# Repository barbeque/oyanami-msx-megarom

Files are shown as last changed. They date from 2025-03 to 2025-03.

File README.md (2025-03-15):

# Oyanami
TODO: Overview

This project was built as part of a [Leaded Solder blog](https://www.leadedsolder.com/) entry.

Articles so far about this project:
 - [Oya, I've heard of Mega-ROMs](https://www.leadedsolder.com/2024/09/03/msx-megarom-oyanami.html)

If it's useful to you, please consider supporting the blog through [Patreon](https://patreon.com/leadedsolder) or [Ko-Fi](https://ko-fi.com/leadedsolder). All money goes directly to future projects like this.

## Build It Yourself!
The Oyanami board is open-source. You can grab the Gerber files from [the Releases page](https://github.com/barbeque/oyanami-msx-megarom/releases) and send those to a fabricator of your choice.

Recommended settings: 

 - ENIG or Hard Gold finishing
 - Beveled or chamfered edge connector

## Known Working Games
 - 1942 (MSX2 version only)
 - Arkanoid 2 - Revenge of DOH
 - Ashguine Story I
 - Bubble Bobble
 - Contra (MSX2; CRC32: 4e82660d)
 - Cyborg Z
 - Digital Devil Story
 - Dragon Buster
 - Dragon Quest 1 (both MSX1, MSX2 versions)
 - Druid
 - F1 Spirit
 - Family Billiards
 - Fantasy Zone 1
 - Final Zone Wolf
 - Ganbare Goemon
 - Gangjeol Robocop
 - Genesis - Dawn of a New Day
 - Hai No Majutsushi
 - Hinotori
 - King Kong 2
 - King's Valley 2 Edit Contest Edition
 - King's Valley 2 (MSX2 only)
 - Metal Gear (CRC32: e85c5731)
 - Mr. Ninja Ashura's Chapter
 - Nemesis (CRC32: 4dfcc009)
 - Nemesis 2
 - Parodius
 - Pengo
 - Penguin Adventure
 - Pennant Race
 - Return of Jelda
 - Salamander
 - Spy vs. Spy II (64kB Konami-mapper version)
 - Seikima 2 Special - Tetsuji
 - Street Master
 - Super Bioman 4
 - Super Boy 3
 - Super Runner
 - Tengoku Yoitoko - Heaven
 - The Fairyland Story
 - The Fantasm Soldier Valis
 - The Maze of Galious: Knightmare 2
 - Topple Zip MSX2
 - Treasure of USAS (MSX2)
 - Vampire Killer (MSX2)
 - Wonsiin
 - Young Sherlock: Legacy of Doyle

This is an incomplete list, please submit pull requests for any other games you have tested.

## Bill of Materials

| Position | Component | Digi-Key link | Comments  |
|---|---|---|---|
| U1 | SST39SF040 DIP EEPROM | | |
| U3 | 74LS670 DIP | | Do not use ALS, see below |
| U4 | 74LS02 DIP | | |
| C... | 0.1µF through-hole ceramic capacitor | | |
| RN1 | 10kΩ x 8 (9-pin SIP) resistor network | | |
| SW1 | 2-pin DIP switch | | |

I also recommend getting a case for the PCB from somewhere like [Retro Game Restore](https://retrogamerestore.com/store/msx_cart_shell).

Beware! Using socketed ICs may not leave enough vertical height for a standard Konami-style cartridge case to close.

74ALS670 has been reported not to work with MSX Turbo-R systems. Please use only the LS variant.

## Version History
### v1.2: In development
Still in development. Adds write-enable pin to ROM to support in-MSX reflashing.

### v1.1: July 2024
Initial working version. Supports read-only games.

## Special Thanks
 - bsittler for the help and inspiration to get this figured out;
 - Pax for CRC32s;
 - Annual_Bottle_4639 on Reddit for testing additional games

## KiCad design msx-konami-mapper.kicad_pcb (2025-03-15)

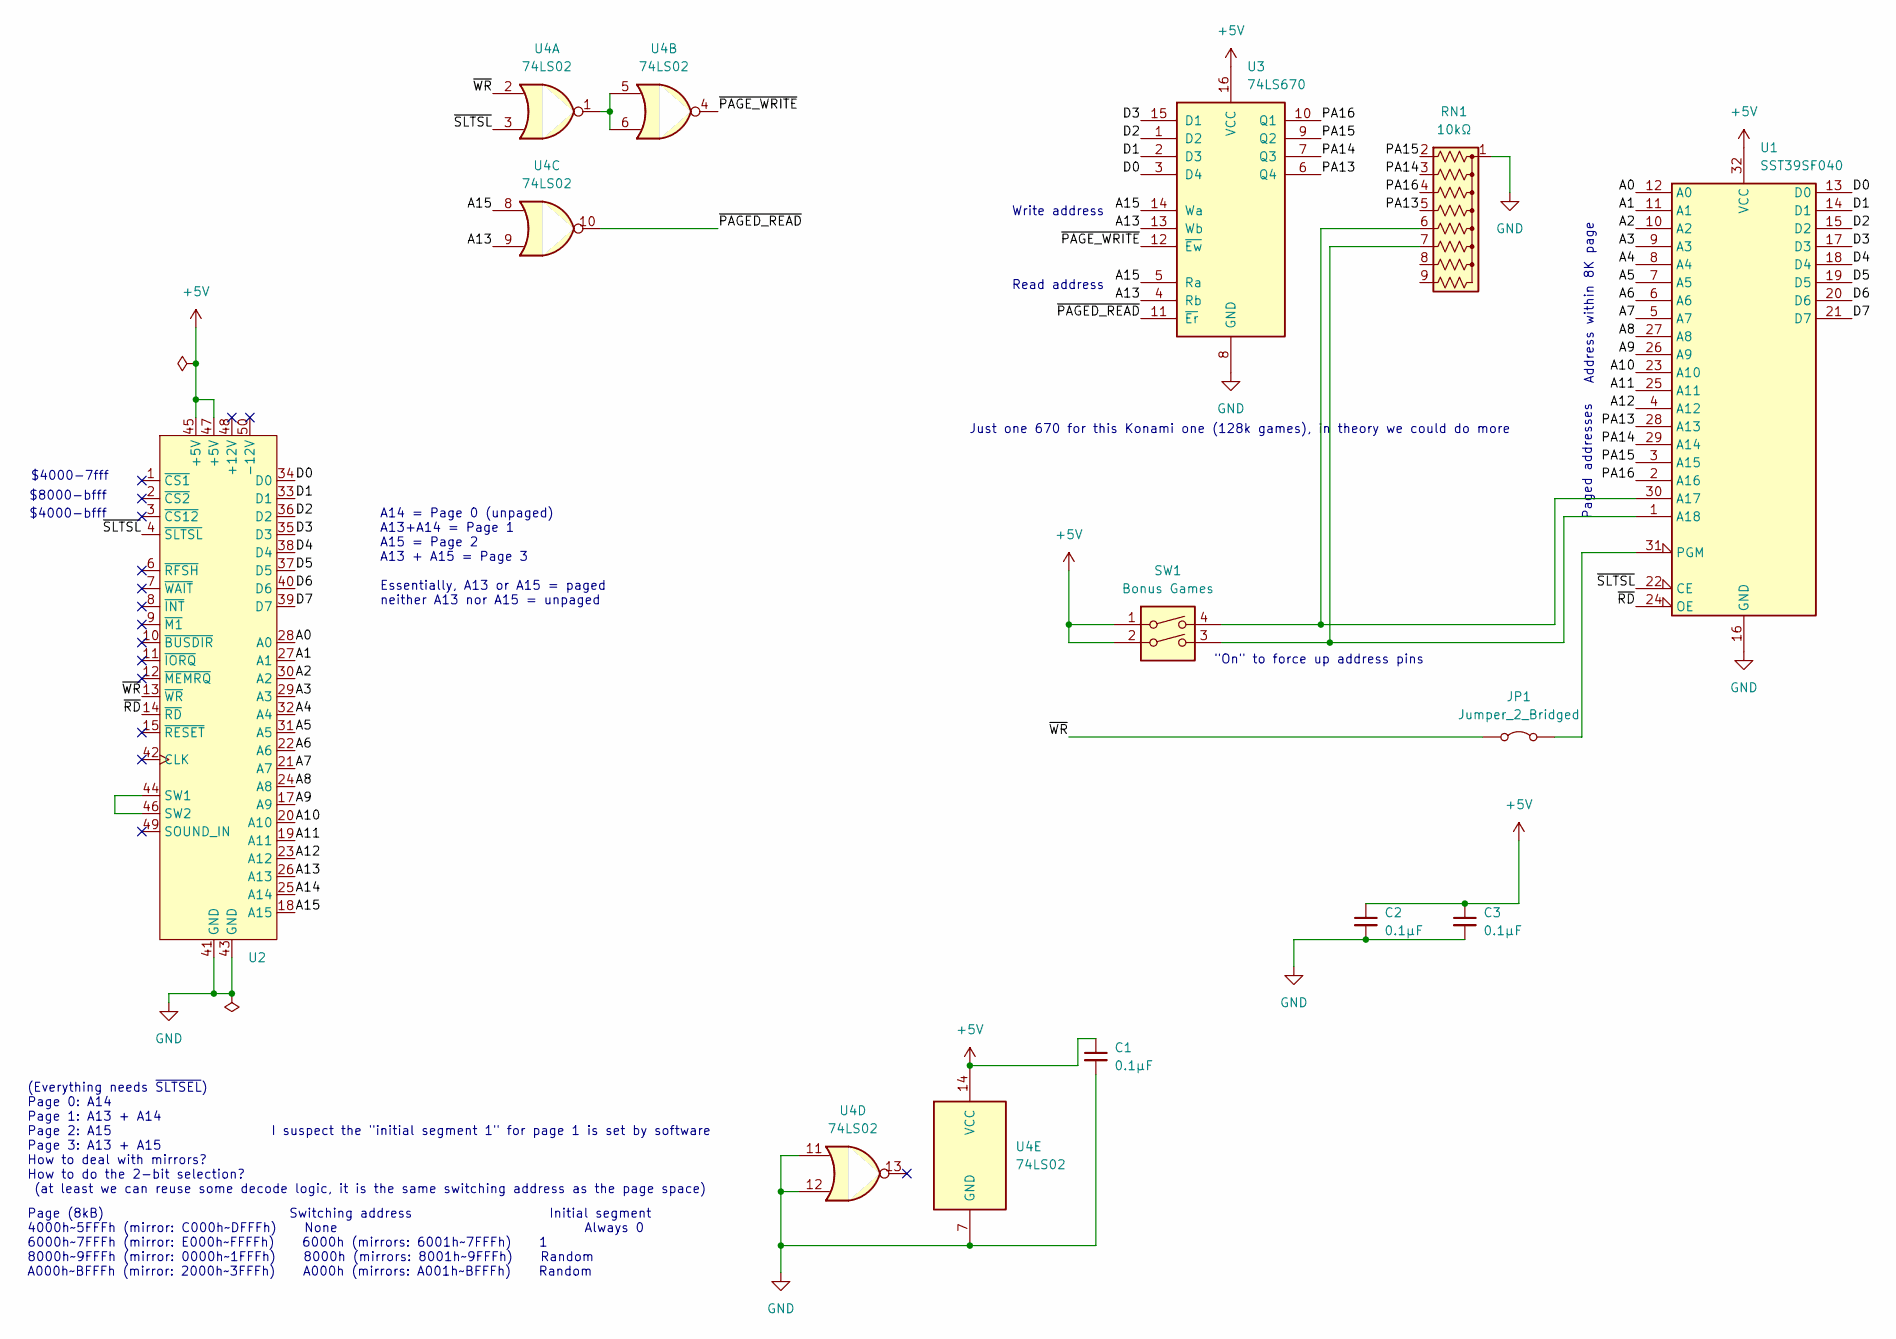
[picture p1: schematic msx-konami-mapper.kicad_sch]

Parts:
C1: 0.1µF; C_Disc_D3.8mm_W2.6mm_P2.50mm
C2, C3: 0.1µF; C_Disc_D3.8mm_W2.6mm_P2.50mm; DigiKey 399-9776-ND
JP1: Jumper_2_Bridged; SolderJumper-2_P1.3mm_Bridged_RoundedPad1.0x1.5mm
RN1: 10kΩ; R_Array_SIP9; DigiKey 4609X-101-103LF-ND
SW1: Bonus Games; SW_DIP_SPSTx02_Slide_9.78x7.26mm_W7.62mm_P2.54mm; DigiKey 2223-DS01-254-L-02BE-ND
U1: SST39SF040; DIP-32_W15.24mm_Socket_LongPads; DigiKey SST39SF040-70-4C-PHE-ND
U2: Cartridge
U3: 74LS670; DIP-16_W7.62mm_Socket_LongPads; DigiKey 296-34025-5-ND
U4: 74LS02; DIP-14_W7.62mm_Socket_LongPads; DigiKey 296-1627-5-ND

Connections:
+5V: C1.1, C2.1, C3.1, SW1.1, SW1.2, U1.32 (VCC), U2.45 (+5V), U2.47 (+5V), U3.16 (VCC), U4.14 (VCC)
/A0: U1.12 (A0), U2.28 (A0)
/A1: U1.11 (A1), U2.27 (A1)
/A2: U1.10 (A2), U2.30 (A2)
/A3: U1.9 (A3), U2.29 (A3)
/A4: U1.8 (A4), U2.32 (A4)
/A5: U1.7 (A5), U2.31 (A5)
/A6: U1.6 (A6), U2.22 (A6)
/A7: U1.5 (A7), U2.21 (A7)
/A8: U1.27 (A8), U2.24 (A8)
/A9: U1.26 (A9), U2.17 (A9)
/A10: U1.23 (A10), U2.20 (A10)
/A11: U1.25 (A11), U2.19 (A11)
/A12: U1.4 (A12), U2.23 (A12)
/A13: U2.26 (A13), U3.4 (Rb), U3.13 (Wb), U4.9
/A14: U2.25 (A14)
/A15: U2.18 (A15), U3.5 (Ra), U3.14 (Wa), U4.8
/D0: U1.13 (D0), U2.34 (D0), U3.3 (D4)
/D1: U1.14 (D1), U2.33 (D1), U3.2 (D3)
/D2: U1.15 (D2), U2.36 (D2), U3.1 (D2)
/D3: U1.17 (D3), U2.35 (D3), U3.15 (D1)
/D4: U1.18 (D4), U2.38 (D4)
/D5: U1.19 (D5), U2.37 (D5)
/D6: U1.20 (D6), U2.40 (D6)
/D7: U1.21 (D7), U2.39 (D7)
/PA13: RN1.5 (R4), U1.28 (A13), U3.6 (Q4)
/PA14: RN1.3 (R2), U1.29 (A14), U3.7 (Q3)
/PA15: RN1.2 (R1), U1.3 (A15), U3.9 (Q2)
/PA16: RN1.4 (R3), U1.2 (A16), U3.10 (Q1)
/~PAGED_READ: U3.11 (~Er), U4.10
/~PAGE_WRITE: U3.12 (~Ew), U4.4
/~RD: U1.24 (OE), U2.14 (~RD)
/~SLTSL: U1.22 (CE), U2.4 (~SLTSL), U4.3
/~WR: JP1.1 (A), U2.13 (~WR), U4.2
GND: C1.2, C2.2, C3.2, RN1.1 (common), U1.16 (GND), U2.41 (GND), U2.43 (GND), U3.8 (GND), U4.7 (GND), U4.11, U4.12
unnamed: JP1.2 (B), U1.31 (PGM)
unnamed: RN1.6 (R5), SW1.4, U1.30 (A17)
unnamed: RN1.7 (R6), SW1.3, U1.1 (A18)
unnamed: U2.44 (SW1), U2.46 (SW2)
unnamed: U4.1, U4.5, U4.6

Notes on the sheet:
Paged addresses
Write address
Address within 8K page
A14 = Page 0 (unpaged) A13+A14 = Page 1 A15 = Page 2 A13 + A15 = Page 3 Essentially, A13 or A15 = paged neither A13 nor A15 = unpaged
$8000-bfff
$4000-7fff
Read address
$4000-bfff
Page (8kB) Switching address Initial segment 4000h~5FFFh (mirror: C000h~DFFFh) None Always 0 6000h~7FFFh (mirror: E000h~FFFFh) 6000h (mirrors: 6001h~7FFFh) 1 8000h~9FFFh (mirror: 0000h~1FFFh) 8000h (mirrors: 8001h~9FFFh) Random A000h~BFFFh (mirror: 2000h~3FFFh) A000h (mirrors: A001h~BFFFh) Random
"On" to force up address pins
I suspect the "initial segment 1" for page 1 is set by software
(Everything needs ~{SLTSEL}) Page 0: A14 Page 1: A13 + A14 Page 2: A15 Page 3: A13 + A15 How to deal with mirrors? How to do the 2-bit selection? (at least we can reuse some decode logic, it is the same switching address as the page space)
Just one 670 for this Konami one (128k games), in theory we could do more

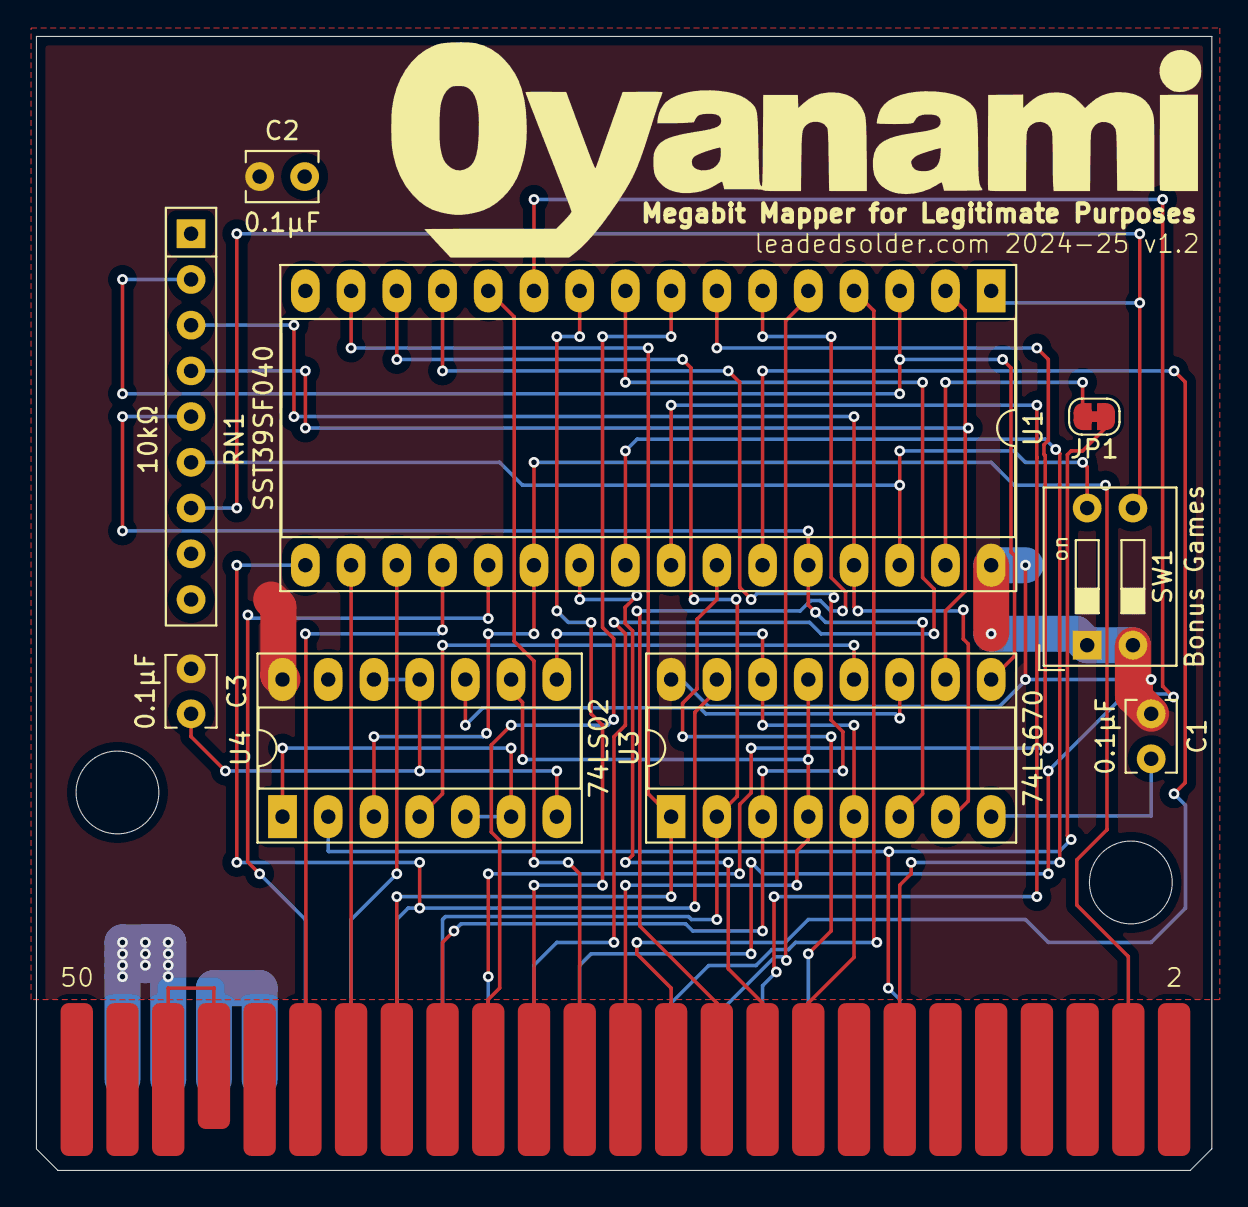
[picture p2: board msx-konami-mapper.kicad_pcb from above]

Board: 2 copper layers, 65.3 x 63.0 mm, 10 parts (0 on the bottom side), 39 nets.

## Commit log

2024-06-27 Oyanami logo, rough board dims
    [msx-konami-mapper.kicad_pcb, msx-konami-mapper.kicad_sch]
2024-06-27 Placed EPROM, I may regret this
    [msx-konami-mapper.kicad_pcb, msx-konami-mapper.kicad_sch]
2024-06-28 Edge connector
    [msx-konami-mapper.kicad_pcb, msx-konami-mapper.kicad_sch]
2024-06-28 Put the connector the right way around, dimwit
    [msx-konami-mapper.kicad_pcb, msx-konami-mapper.kicad_sch]
2024-06-28 Data pins
    [msx-konami-mapper.kicad_pcb, msx-konami-mapper.kicad_sch]
2024-06-28 Super gross data bus I'll probably tear up later
    [msx-konami-mapper.kicad_pcb]
2024-06-28 Wipe the data bus after all
    [msx-konami-mapper.kicad_pcb]
2024-06-28 Disable programming for v1.0
    [msx-konami-mapper.kicad_pcb, msx-konami-mapper.kicad_sch]
2024-06-28 The mysteries of decoding
    [msx-konami-mapper.kicad_sch]
2024-06-28 Starting to puzzle this out
    [msx-konami-mapper.kicad_sch]
2024-06-28 Notes to self
    [msx-konami-mapper.kicad_sch]
2024-06-28 Experimental dual-game select
    [msx-konami-mapper.kicad_pcb, msx-konami-mapper.kicad_sch]
2024-06-28 Yes, I need another 670
    [msx-konami-mapper.kicad_sch]
2024-06-28 Driving 8 bits of pages
    [msx-konami-mapper.kicad_pcb, msx-konami-mapper.kicad_sch]
2024-06-28 Undoing bad work
    [msx-konami-mapper.kicad_sch]
2024-06-28 I think this works
    [msx-konami-mapper.kicad_pcb, msx-konami-mapper.kicad_sch]
2024-07-04 V1.1 begins... worried about C1 being too close to mounting hole
    [msx-konami-mapper.kicad_pcb]
2024-07-10 Widen holes to fit into case better
    [msx-konami-mapper.kicad_pcb]
2024-07-10 Add 'rear' tag
    [msx-konami-mapper.kicad_pcb]
2024-07-15 Pull-downs for '670 output
    [msx-konami-mapper.kicad_pcb, msx-konami-mapper.kicad_sch]
2024-07-15 Fix DIP switch being backward
    [msx-konami-mapper.kicad_pcb, msx-konami-mapper.kicad_sch]
2024-07-15 Prepare v1.1 for release
    [msx-konami-mapper.kicad_pcb]
2024-07-15 Remove some parts
    [msx-konami-mapper.kicad_pcb, msx-konami-mapper.kicad_sch]
2024-07-15 Better explainer
    [msx-konami-mapper.kicad_sch]
2024-07-29 Case warning
2025-02-03 Prepare for BOM release
    [msx-konami-mapper.kicad_sch]
2025-02-03 DK part numbers
    [msx-konami-mapper.kicad_sch]
2025-02-07 CRC for Metal Gear
2025-03-15 KiCad 9; add WR to ROM; fix +5V weak trace
    [msx-konami-mapper.kicad_pcb, msx-konami-mapper.kicad_sch]
